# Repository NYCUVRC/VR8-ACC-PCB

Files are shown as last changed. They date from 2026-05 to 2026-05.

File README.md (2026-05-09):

VR8-ACC-PCB
VR8-ACC-PCB-connectors sim
圖片
圖片

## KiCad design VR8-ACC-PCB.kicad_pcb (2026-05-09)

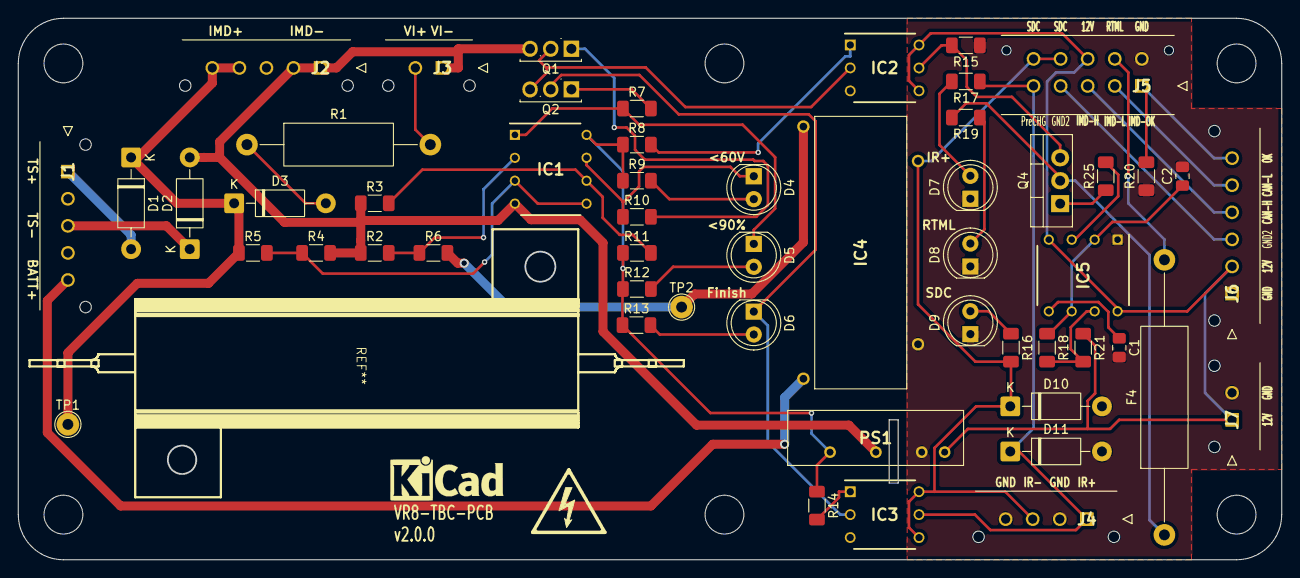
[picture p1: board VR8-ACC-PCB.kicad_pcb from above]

Board: 2 copper layers, 140.0 x 60.0 mm, 60 parts (0 on the bottom side), 42 nets.

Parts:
C1: 0.01u; C_0805_2012Metric_Pad1.18x1.45mm_HandSolder
C2: 4.7u; C_0805_2012Metric_Pad1.18x1.45mm_HandSolder
D1, D2, D10, D11: 1N4007; D_DO-41_SOD81_P10.16mm_Horizontal
D3: 62V; D_DO-41_SOD81_P10.16mm_Horizontal
D4, D5, D6, D7, D8, D9: LED; LED_D5.0mm
F4: Fuse; R_Axial_DIN0516_L15.5mm_D5.0mm_P30.48mm_Horizontal
H1, H2, H3, H4, H5, H6: MountingHole; MountingHole_4.3mm_M4
IC1: LM393P; DIP794W53P254L959H508Q8N
IC2, IC3: VO14642AT; DIP762W60P254L760H470Q6N
IC4: KT12-1A-40L-THT; KT121A40LTHT
IC5: NE555P; DIP794W53P254L959H508Q8N
J1, J2: 43650-0516; 43650-05YY_151617
J3, J7: 43650-0216; 43650-02YY_151617
J4: 43650-0416; 43650-04YY_151617
J5: 43045-1013; 43045-10YY_121314
J6: 43650-0616; 43650-06YY_151617
PS1: SPU01M-12; SPU01M12
Q1, Q2: Q_NMOS_Depletion_GDS; TO-251-3_Vertical
Q4: Q_PMOS_GDS; TO-220-3_Vertical
R1: 200k; R_Axial_DIN0414_L11.9mm_D4.5mm_P20.32mm_Horizontal
R2: 51k; R_1206_3216Metric_Pad1.30x1.75mm_HandSolder
R3: 3.3k; R_1206_3216Metric_Pad1.30x1.75mm_HandSolder
R4: 56k; R_1206_3216Metric_Pad1.30x1.75mm_HandSolder
R5, R6: 3.3M; R_1206_3216Metric_Pad1.30x1.75mm_HandSolder
R7, R8, R9, R10, R12, R13, R14, R15, R16, R17, R19, R25: 10k; R_1206_3216Metric_Pad1.30x1.75mm_HandSolder
R11: 36k; R_1206_3216Metric_Pad1.30x1.75mm_HandSolder
R18: 47k; R_1206_3216Metric_Pad1.30x1.75mm_HandSolder
R20: 2.2k; R_1206_3216Metric_Pad1.30x1.75mm_HandSolder
R21: 1k; R_1206_3216Metric_Pad1.30x1.75mm_HandSolder
TP1, TP2: TestPoint; TestPoint_THTPad_D2.5mm_Drill1.2mm

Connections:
BATT+: IC4.2 (COM), J1.5
Chassis_Ground: J5.4, J6.3
GLV_12V: IC2.4 (S'), IC2.6 (S), IC5.4 (RESET), IC5.8 (VCC), J5.8, J6.2, J7.1, PS1.1 (+VIN), R21.1
GND: C1.2, C2.2, D7.1 (K), D8.1 (K), D9.1 (K), D10.2 (A), D11.2 (A), IC4.3 (COIL_1), IC5.1 (GND), J4.2, J4.4, J5.6, J6.1, J7.2, PS1.2 (-VIN), R15.1, R20.1
HV+: IC4.1 (NO), R6.2, TP2.1 (1_1)
HV_12V: IC1.8 (VCC), PS1.6 (+VOUT), R8.1, R9.1, R11.1, R12.1, R13.1, R14.1
IMD_CAN_H: J5.3, J6.4
IMD_CAN_L: J5.2, J6.5
IMD_Status: J5.1, J6.6, R20.2
IR+_ctrl: D11.1 (K), IC3.5 (DC), J4.1, J5.5, R17.1
unnamed: D1.2 (A), J1.1
unnamed: D2.1 (K), J1.3
unnamed: D3.2 (A), R1.1
unnamed: D4.2 (A), R9.2
unnamed: D5.2 (A), R12.2
unnamed: D6.2 (A), R13.2
unnamed: D6.1 (K), IC3.2 (K), Q2.2 (D)
unnamed: D7.2 (A), R17.2
unnamed: D8.2 (A), R19.1
unnamed: D9.2 (A), R16.1
unnamed: IC1.3 (1IN+), IC1.5 (2IN+), R4.1, R5.2
unnamed: IC1.2 (1IN-), R2.2, R6.1
unnamed: IC1.6 (2IN-), R3.2, R11.2
unnamed: IC2.1 (A), R8.2
unnamed: IC2.2 (K), Q1.2 (D), Q2.3 (S)
unnamed: IC3.1 (A), R14.2
unnamed: C1.1, IC5.5 (CONT)
unnamed: IC5.7 (DISCH), R18.2, R21.2
unnamed: IC5.3 (OUT), R25.2
unnamed: C2.1, IC5.2 (TRIG), IC5.6 (THRES), R18.1
unnamed: Q1.1 (G), R10.2
unnamed: Q2.1 (G), R7.2
unnamed: F4.1, Q4.2 (D), R19.2
unnamed: Q4.1 (G), R25.1
OK_60V: D4.1 (K), IC1.7 (2OUT), R10.1
OK_90%: D5.1 (K), IC1.1 (1OUT), R7.1
RTML: F4.2, J5.7
RTML_enable: IC2.5 (DC), Q4.3 (S), R15.2
SDC_final: D10.1 (K), IC3.4 (S'), IC3.6 (S), IC4.4 (COIL_2), J4.3, J5.9, J5.10, R16.2
TS+: D1.1 (K), D3.1 (K), J2.4, J2.5, R5.1, TP1.1 (1_1)
TS-: D2.2 (A), IC1.4 (GND), J2.1, J2.2, J3.1, PS1.4 (-VOUT), Q1.3 (S), R2.1, R3.1, R4.2
VI+: J3.2, R1.2

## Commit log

2026-01-24 add some silkscreens
    [VR8-ACC-PCB.kicad_pcb, connectors&sim.kicad_sch]
2026-01-24 add HV/LV boundary silkscreen
    [VR8-ACC-PCB.kicad_pcb]
2026-01-24 add mouser part numbers
    change resisters footprints of 0805 to 1206 for 500V voltage rating
    [VR8-ACC-PCB.kicad_pcb, VR8-ACC-PCB.kicad_sch, connectors&sim.kicad_sch]
2026-01-24 fix date
    [VR8-ACC-PCB.kicad_pcb, VR8-ACC-PCB.kicad_sch, connectors&sim.kicad_sch]
2026-01-24 J5 reorientation
    [VR8-ACC-PCB.kicad_pcb, connectors&sim.kicad_sch]
2026-01-25 J4 reorientation
    [VR8-ACC-PCB.kicad_pcb, VR8-ACC-PCB.kicad_sch]
2026-01-25 update version
    [VR8-ACC-PCB.kicad_pcb]
2026-01-27 add ne555 output resister
    [VR8-ACC-PCB.kicad_pcb, VR8-ACC-PCB.kicad_sch]
2026-02-15 fix wrong DCDC & precharge relay pin connection
    swap out +/out - of the DCDC
    swap coil/contact of the relay
    [VR8-ACC-PCB.kicad_pcb, VR8-ACC-PCB.kicad_sch]
2026-05-09 find and fix test errors, some improvement
    1. remove onboard fuse (now is inline)
    2. change RTML nmos to pmos (to make nmos on, RTML only have V_G-V_th=10V, which is not enough to drive RTML)
    3. new voltage divider config (resistors tolerance is matter, <1% is better)
    4. add IR+_ctrl signal output to J5
    5. J7 is now used for powering Arduino rather than bridging interlock signal (SDC_after_MSD is removed from J5 as well)
    6. explain the working principle on sch
    7. move to kicad 10
    [VR8-ACC-PCB.kicad_pcb, VR8-ACC-PCB.kicad_sch, connectors&sim.kicad_sch]
